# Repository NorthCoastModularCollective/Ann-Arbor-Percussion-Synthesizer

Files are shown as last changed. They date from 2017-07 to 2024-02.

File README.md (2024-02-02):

# Ann Arbor Percussion Synthesizer

A module that generates “abstract” percussion sounds and has a fairly simple interface. It won’t be intended to create “bass drums” or “snares” or “hi hats”, though it’ll probably be able to make things that approximate those sounds. It is raw, dirty, glitchy, lo-fi, and abstract. A Banksy interpretation of a Dali painting of industrial-steam-punk-Qbert. Interacting with it gives you a feeling of exploration and discovery with little emphasis on predictability and reproducibility. However, great care was taken to make the experience not feel like pure chaos and randomness. 

CAUTION: this project is still in development. There are many bugs and gaps. 

Audio Sample, [here](https://soundcloud.com/verzerren/ann-arbor-percussion-synthesizer-v-001-sound-sample)

https://github.com/NorthCoastModularCollective/Ann-Arbor-Percussion-Synthesizer/assets/6989685/e6aa8b81-97f8-49d5-8cca-bbeed19dbfc6

Hardware Overview:
- Teensy 4.1
- Teensy Audio Library
- Eurorack Trigger/Gate input

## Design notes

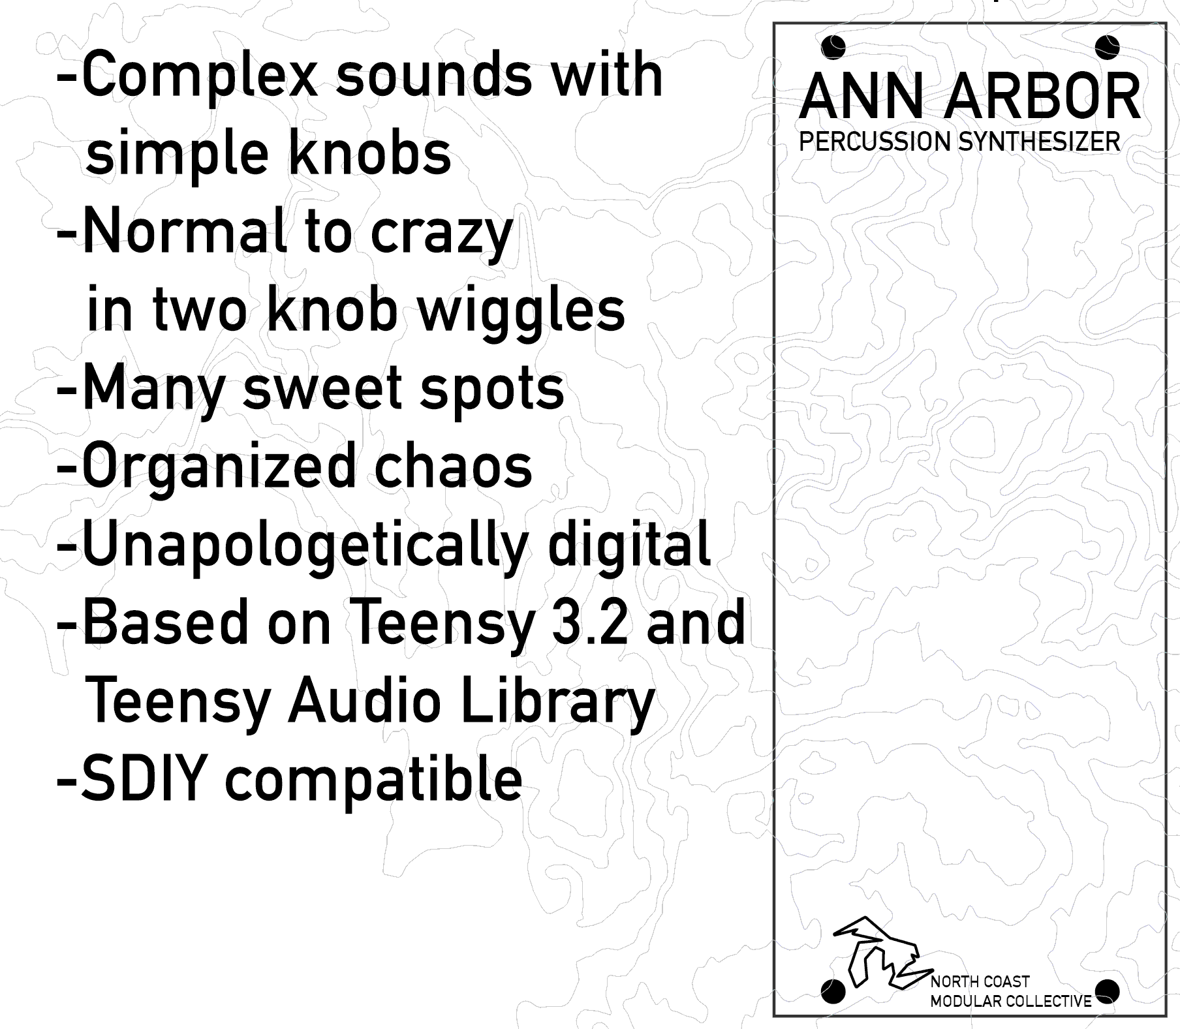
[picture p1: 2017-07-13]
A2Perc.gif

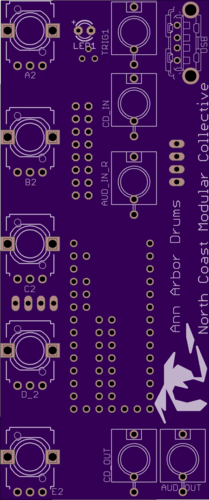
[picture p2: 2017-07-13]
A2_Perc_Front.png

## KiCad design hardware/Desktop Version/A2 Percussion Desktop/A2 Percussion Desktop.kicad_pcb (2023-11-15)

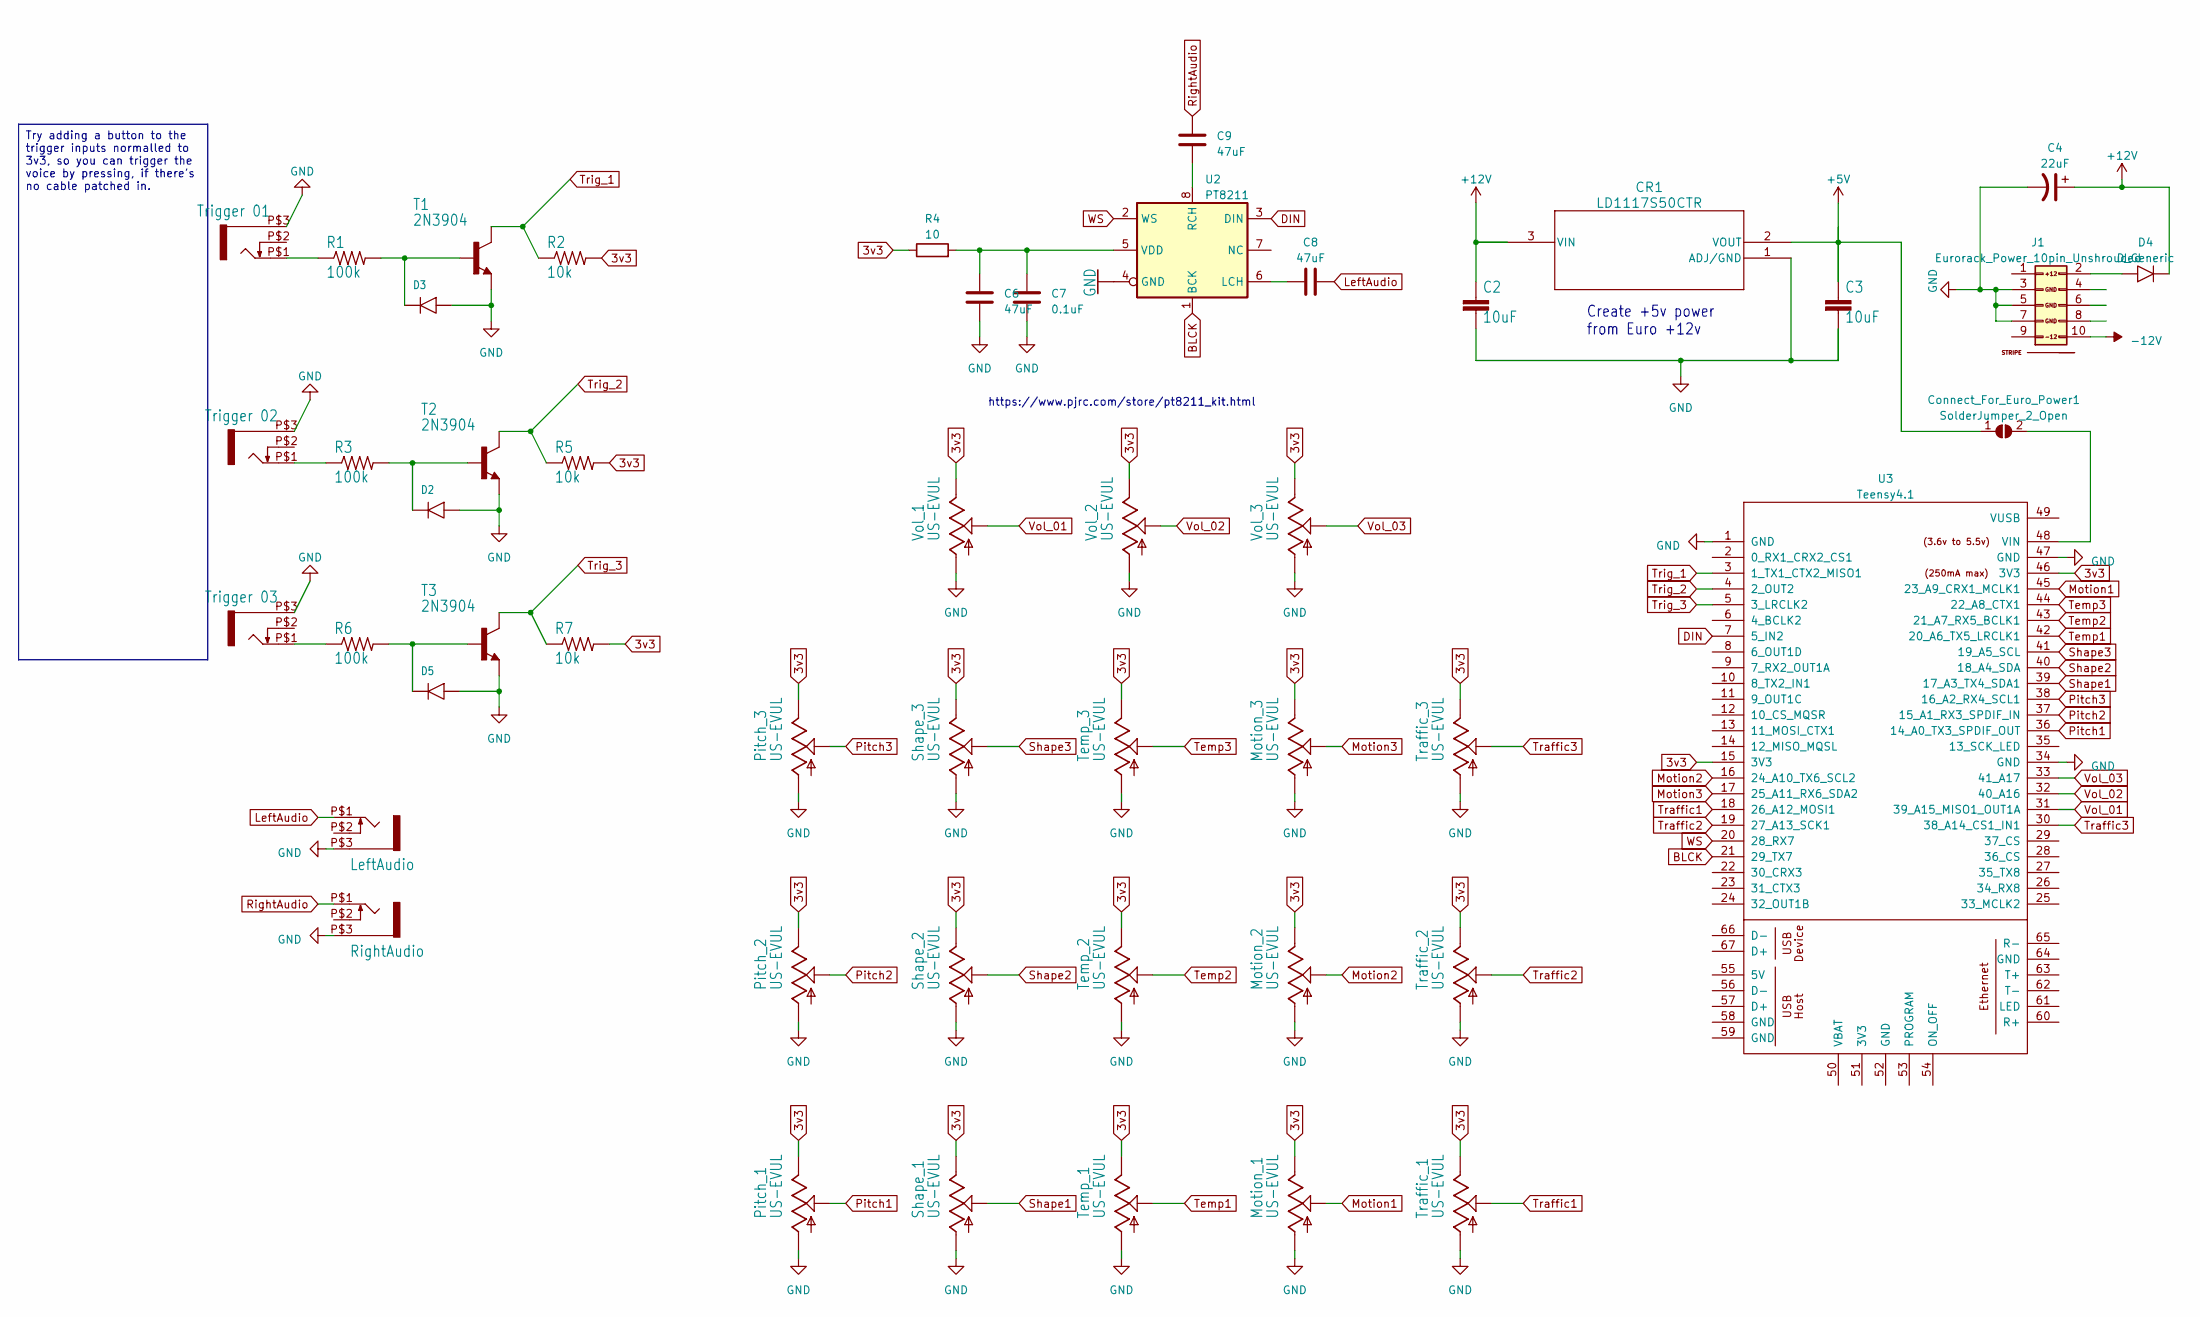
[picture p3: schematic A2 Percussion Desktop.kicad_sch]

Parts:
C2, C3: 10uF; C_Disc_D4.3mm_W1.9mm_P5.00mm
C4: 22uF; CP_Radial_D5.0mm_P2.50mm
C6, C8, C9: 47uF; C_Axial_L5.1mm_D3.1mm_P7.50mm_Horizontal
C7: 0.1uF; C_Axial_L5.1mm_D3.1mm_P7.50mm_Horizontal
CR1: LD1117S50CTR; SOT-223_STM
Connect_For_Euro_Power1: SolderJumper_2_Open; JUMPER_SMD_1x2
D2, D3, D5: DIODESOD-123; D_DO-35_P7.62mm_Horizontal
D4: D_Generic; D_DO-35_P7.62mm_Horizontal
J1: Eurorack_Power_10pin_Unshrouded; Pins_2x05_2.54mm_TH_Europower; Part Number 1-1002FBV0T
LeftAudio1: LeftAudio; WQP-PJ301M-12_JACK
Motion_1, Motion_2, Motion_3: US-EVUL; EVUFXL
Pitch_1, Pitch_2, Pitch_3: US-EVUL; EVUFXL
R1, R3, R6: 100k; R_Axial_DIN0207_L6.3mm_D2.5mm_P7.62mm_Horizontal
R2, R5, R7: 10k; R_Axial_DIN0207_L6.3mm_D2.5mm_P7.62mm_Horizontal
R4: 10; R_Axial_DIN0207_L6.3mm_D2.5mm_P7.62mm_Horizontal
RightAudio1: RightAudio; WQP-PJ301M-12_JACK
Shape_1, Shape_2, Shape_3: US-EVUL; EVUFXL
T1, T2, T3: 2N3904; TO92
TRIG1: Trigger 01; WQP-PJ301M-12_JACK
TRIG2: Trigger 02; WQP-PJ301M-12_JACK
TRIG3: Trigger 03; WQP-PJ301M-12_JACK
Temp_1, Temp_2, Temp_3: US-EVUL; EVUFXL
Traffic_1, Traffic_2, Traffic_3: US-EVUL; EVUFXL
U2: PT8211; VSSOP-8_3.0x3.0mm_P0.65mm
U3: Teensy4.1; Teensy41
Vol_1, Vol_2, Vol_3: US-EVUL; EVUFXL

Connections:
3v3: Motion_1.3 (E), Motion_2.3 (E), Motion_3.3 (E), Pitch_1.3 (E), Pitch_2.3 (E), Pitch_3.3 (E), R2.2, R4.1, R5.2, R7.2, Shape_1.3 (E), Shape_2.3 (E), Shape_3.3 (E), Temp_1.3 (E), Temp_2.3 (E), Temp_3.3 (E), Traffic_1.3 (E), Traffic_2.3 (E), Traffic_3.3 (E), U3.15 (3V3), U3.46 (3V3), Vol_1.3 (E), Vol_2.3 (E), Vol_3.3 (E)
+5V: C3.1, CR1.2 (VOUT), Connect_For_Euro_Power1.1 (A)
+12V: C2.1, C4.1, CR1.3 (VIN), D4.1 (K)
-12V: J1.10 (-12V)
BLCK: U2.1 (BCK), U3.21 (29_TX7)
DIN: U2.3 (DIN), U3.7 (5_IN2)
GND: C2.2, C3.2, C4.2, C6.2, C7.2, CR1.1 (ADJ/GND), D2.2 (A), D3.2 (A), D5.2 (A), J1.3 (GND), J1.5 (GND), J1.7 (GND), LeftAudio1.P$3 (1), Motion_1.1 (A), Motion_2.1 (A), Motion_3.1 (A), Pitch_1.1 (A), Pitch_2.1 (A), Pitch_3.1 (A), RightAudio1.P$3 (1), Shape_1.1 (A), Shape_2.1 (A), Shape_3.1 (A), T1.3 (E), T2.3 (E), T3.3 (E), TRIG1.P$3 (1), TRIG2.P$3 (1), TRIG3.P$3 (1), Temp_1.1 (A), Temp_2.1 (A), Temp_3.1 (A), Traffic_1.1 (A), Traffic_2.1 (A), Traffic_3.1 (A), U2.4 (GND), U3.1 (GND), U3.34 (GND), U3.47 (GND), Vol_1.1 (A), Vol_2.1 (A), Vol_3.1 (A)
LeftAudio: C8.2, LeftAudio1.P$1 (2)
Motion1: Motion_1.2 (S), U3.45 (23_A9_CRX1_MCLK1)
Motion2: Motion_2.2 (S), U3.16 (24_A10_TX6_SCL2)
Motion3: Motion_3.2 (S), U3.17 (25_A11_RX6_SDA2)
unnamed: Connect_For_Euro_Power1.2 (B), U3.48 (VIN)
unnamed: D2.1 (K), R3.2, T2.2 (B)
unnamed: D3.1 (K), R1.2, T1.2 (B)
unnamed: D4.2 (A), J1.2 (+12V)
unnamed: D5.1 (K), R6.2, T3.2 (B)
unnamed: R1.1, TRIG1.P$1 (2)
unnamed: R3.1, TRIG2.P$1 (2)
unnamed: R6.1, TRIG3.P$1 (2)
unnamed: C8.1, U2.6 (LCH)
unnamed: C9.1, U2.8 (RCH)
unnamed: C6.1, C7.1, R4.2, U2.5 (VDD)
Pitch1: Pitch_1.2 (S), U3.36 (14_A0_TX3_SPDIF_OUT)
Pitch2: Pitch_2.2 (S), U3.37 (15_A1_RX3_SPDIF_IN)
Pitch3: Pitch_3.2 (S), U3.38 (16_A2_RX4_SCL1)
RightAudio: C9.2, RightAudio1.P$1 (2)
Shape1: Shape_1.2 (S), U3.39 (17_A3_TX4_SDA1)
Shape2: Shape_2.2 (S), U3.40 (18_A4_SDA)
Shape3: Shape_3.2 (S), U3.41 (19_A5_SCL)
Temp1: Temp_1.2 (S), U3.42 (20_A6_TX5_LRCLK1)
Temp2: Temp_2.2 (S), U3.43 (21_A7_RX5_BCLK1)
Temp3: Temp_3.2 (S), U3.44 (22_A8_CTX1)
Traffic1: Traffic_1.2 (S), U3.18 (26_A12_MOSI1)
Traffic2: Traffic_2.2 (S), U3.19 (27_A13_SCK1)
Traffic3: Traffic_3.2 (S), U3.30 (38_A14_CS1_IN1)
Trig_1: R2.1, T1.1 (C), U3.3 (1_TX1_CTX2_MISO1)
Trig_2: R5.1, T2.1 (C), U3.4 (2_OUT2)
Trig_3: R7.1, T3.1 (C), U3.5 (3_LRCLK2)
Vol_01: U3.31 (39_A15_MISO1_OUT1A), Vol_1.2 (S)
Vol_02: U3.32 (40_A16), Vol_2.2 (S)
Vol_03: U3.33 (41_A17), Vol_3.2 (S)
WS: U2.2 (WS), U3.20 (28_RX7)

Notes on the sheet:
Try adding a button to the trigger inputs normalled to 3v3, so you can trigger the voice by pressing, if there's no cable patched in.
Create +5v power from Euro +12v
https://www.pjrc.com/store/pt8211_kit.html

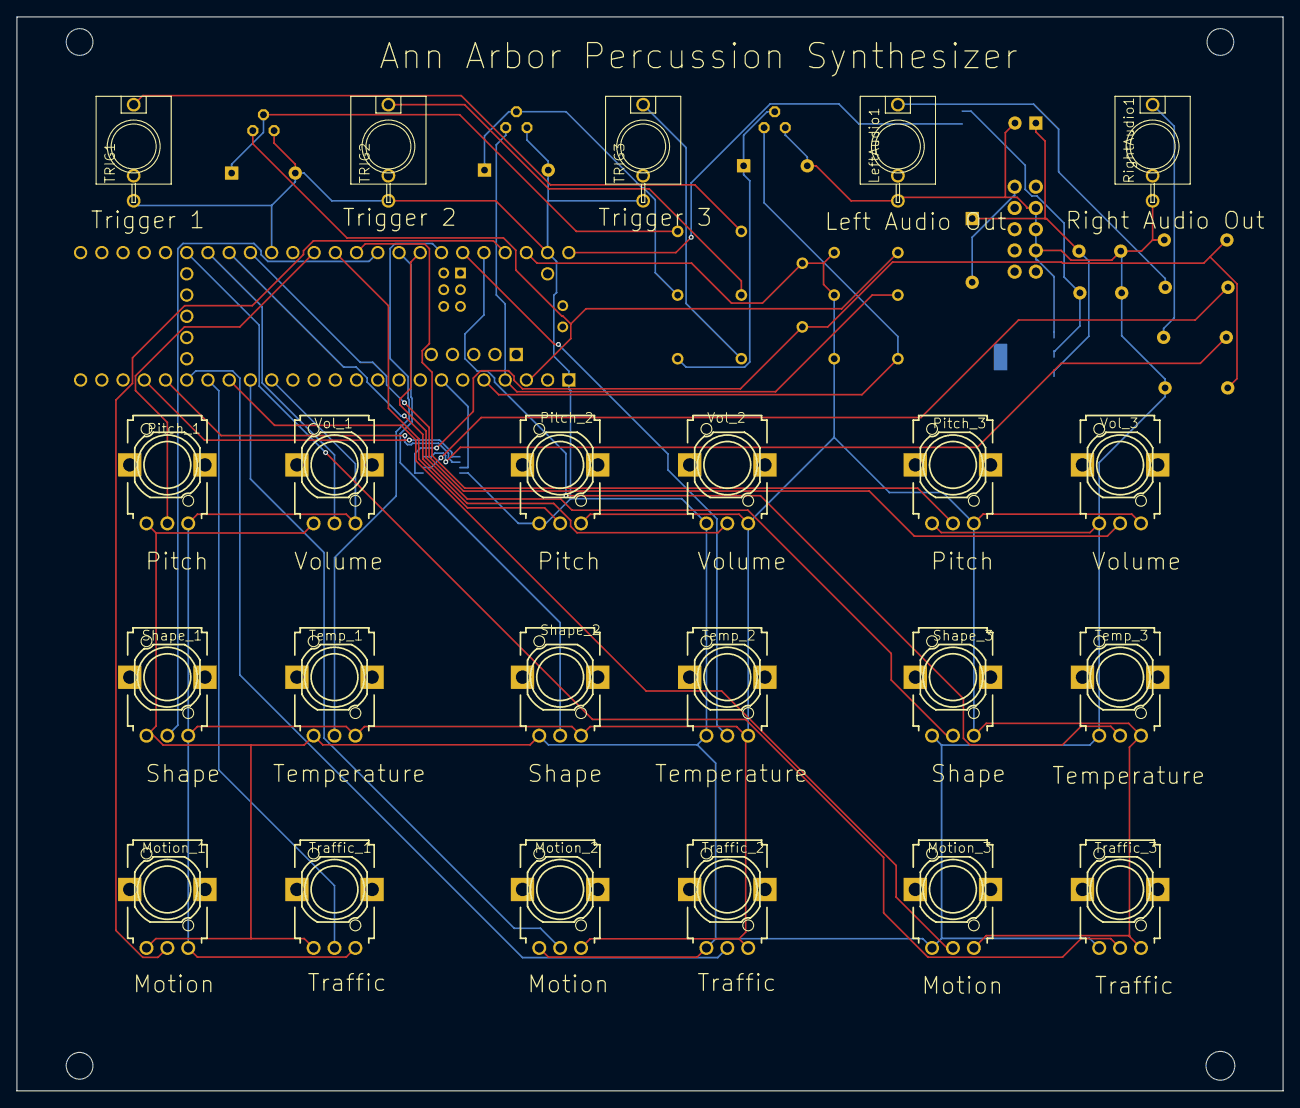
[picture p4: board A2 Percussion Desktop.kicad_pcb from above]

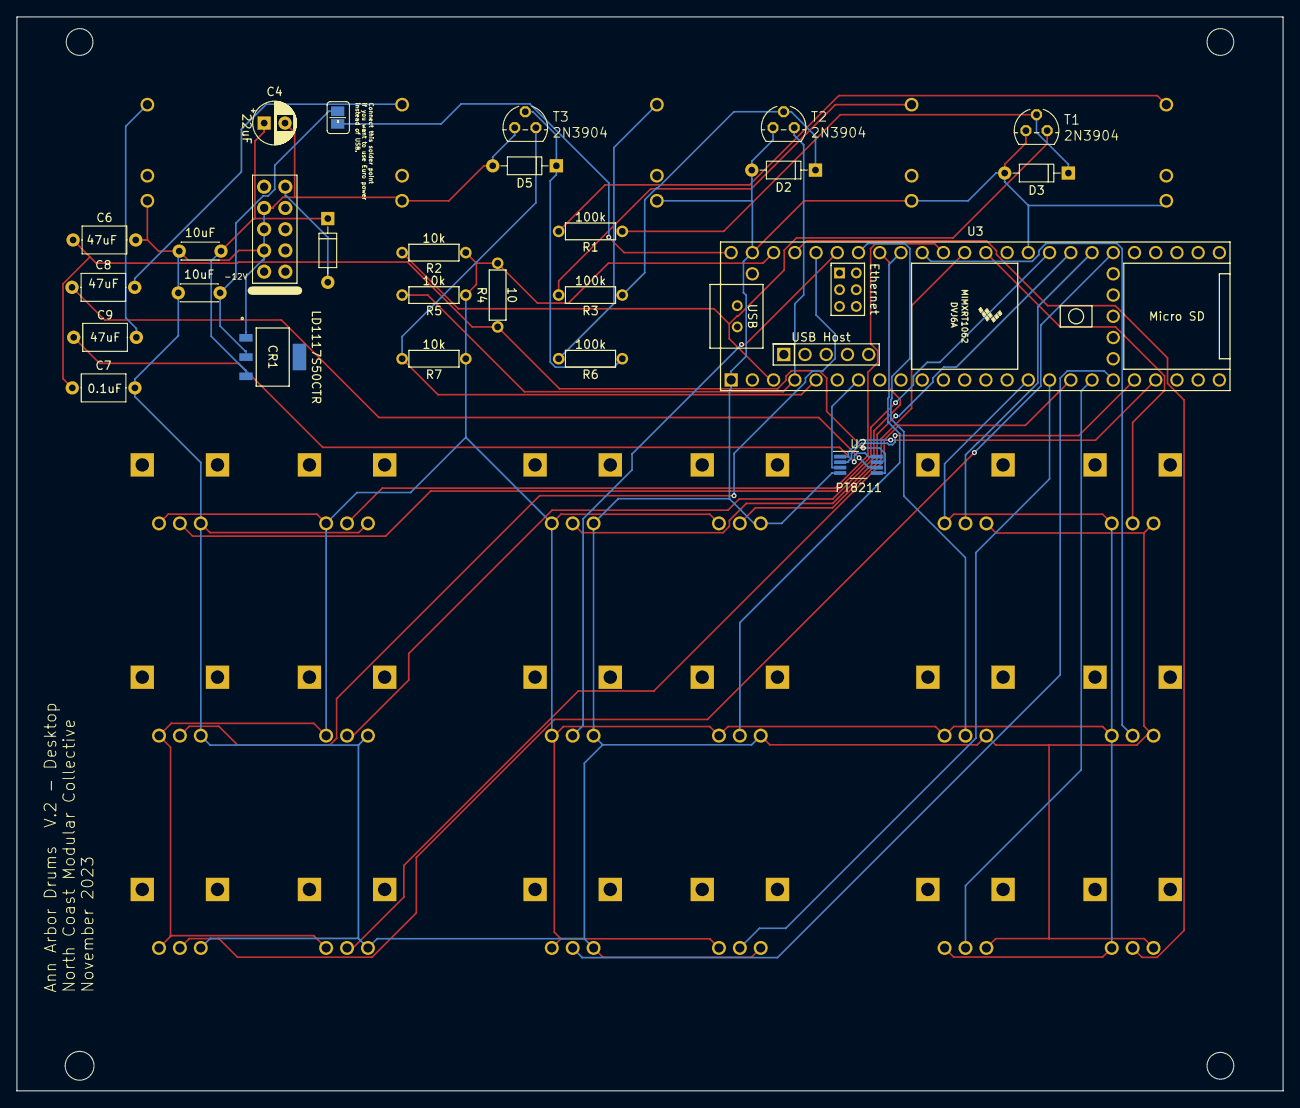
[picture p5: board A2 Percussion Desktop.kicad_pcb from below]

Board: 2 copper layers, 151.5 x 128.5 mm, 49 parts (26 on the bottom side), 41 nets.

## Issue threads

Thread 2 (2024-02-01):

Footprint for PT8211 chip is too small

joebauer, 2024-02-01:

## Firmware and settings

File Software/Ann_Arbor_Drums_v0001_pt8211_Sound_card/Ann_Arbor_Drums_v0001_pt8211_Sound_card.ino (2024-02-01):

/* 
  North Coast Modular Collective Ann Arbor Drums
  Version .001 July 2017
  ---------------------------------------------------------
  Copyright 2017 North Coast Modular Collective
  MIT License:
  Permission is hereby granted, free of charge, to any person obtaining a copy of this software and associated 
  documentation files (the "Software"), to deal in the Software without restriction, including without limitation 
  the rights to use, copy, modify, merge, publish, distribute, sublicense, and/or sell copies of the Software, and 
  to permit persons to whom the Software is furnished to do so, subject to the following conditions:

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
  THE SOFTWARE IS PROVIDED "AS IS", WITHOUT WARRANTY OF ANY KIND, EXPRESS OR IMPLIED, INCLUDING BUT NOT LIMITED TO 
  THE WARRANTIES OF MERCHANTABILITY, FITNESS FOR A PARTICULAR PURPOSE AND NONINFRINGEMENT. IN NO EVENT SHALL THE 
  AUTHORS OR COPYRIGHT HOLDERS BE LIABLE FOR ANY CLAIM, DAMAGES OR OTHER LIABILITY, WHETHER IN AN ACTION OF CONTRACT, 
  TORT OR OTHERWISE, ARISING FROM, OUT OF OR IN CONNECTION WITH THE SOFTWARE OR THE USE OR OTHER DEALINGS IN THE SOFTWARE.
  ----------------------------------------------------------  


  This version uses the pt8211 audio shield
*/


/* Notes to self for future development
Look into MIDI callbacks for handling MIDI input to control the voices https://github.com/FortySevenEffects/arduino_midi_library/wiki/Using-Callbacks


*/

//For modifications, the code from the "GUItool" below can be imported into the Teensy audio system design tool at https://www.pjrc.com/teensy/gui/index.html
#include <Audio.h>
#include <Wire.h>
#include <SPI.h>
#include <SD.h>
#include <SerialFlash.h>

// GUItool: begin automatically generated code
AudioSynthWaveformSine   sine1;          //xy=90,398
AudioSynthWaveformSineModulated sine_fm1;       //xy=260,432
AudioSynthWaveform       waveform1;      //xy=262,328
AudioSynthNoiseWhite     noise1;         //xy=264,493
AudioSynthWaveformPWM    pwm1;           //xy=266,376
AudioSynthSimpleDrum     drum1;          //xy=270,278
AudioMixer4              mixer3;         //xy=437,334
AudioEffectEnvelope      envelope2;      //xy=582,445
AudioEffectEnvelope      envelope1;      //xy=584,333
AudioEffectBitcrusher    bitcrusher1;    //xy=735,334
AudioMixer4              mixer1;         //xy=893,352
AudioFilterStateVariable filter1;        //xy=1041,321
AudioMixer4              mixer2;         //xy=1185,350
AudioOutputPT8211        pt8211_1;       //xy=1338,352
AudioConnection          patchCord1(sine1, pwm1);
AudioConnection          patchCord2(sine1, sine_fm1);
AudioConnection          patchCord3(sine_fm1, 0, mixer3, 3);
AudioConnection          patchCord4(waveform1, 0, mixer3, 1);
AudioConnection          patchCord5(noise1, envelope2);
AudioConnection          patchCord6(pwm1, 0, mixer3, 2);
AudioConnection          patchCord7(drum1, 0, mixer3, 0);
AudioConnection          patchCord8(mixer3, envelope1);
AudioConnection          patchCord9(envelope2, 0, mixer1, 1);
AudioConnection          patchCord10(envelope1, bitcrusher1);
AudioConnection          patchCord11(bitcrusher1, 0, mixer1, 0);
AudioConnection          patchCord12(mixer1, 0, filter1, 0);
AudioConnection          patchCord13(mixer1, 0, mixer2, 2);
AudioConnection          patchCord14(filter1, 0, mixer2, 0);
AudioConnection          patchCord15(filter1, 2, mixer2, 1);
AudioConnection          patchCord16(mixer2, 0, pt8211_1, 0);
AudioConnection          patchCord17(mixer2, 0, pt8211_1, 1);
// GUItool: end automatically generated code




//AudioControlSGTL5000 codec;

//  Set up all the pin number variables
//trigger inputs
int Trigger1Pin = 1; 

//Potentiometers
int pA2 = A0;
int pB2 = A3;
int pC2 = A6;
int pD2 = A9;
int pE2 = A12;

//variables for tracking the trigger states
int playTimes = 0; 

float Drum1Level = 1.0; //Audio level appears to require a float. see if this can be an int!!!!!!!!!!!!!!
float mapf(float x, float in_min, float in_max, float out_min, float out_max)
{
  return (x - in_min) * (out_max - out_min) / (in_max - in_min) + out_min;
}

void setup() {
Serial.begin(9600);

// Get the board ready
  AudioMemory(200);
//  codec.enable();
//  codec.volume(1); //0-1. crank it. We'll control volume per drum channel with the mixers.
  
//Now set up the oscillators  
  AudioNoInterrupts(); 
//Set up drum1
  drum1.frequency(440);
  drum1.length(500);
  drum1.secondMix(0.0);
  drum1.pitchMod(0.50);
//Set up FX
  bitcrusher1.bits(16);
  bitcrusher1.sampleRate(44100);
//Set up noise sources
  noise1.amplitude(.5);
//Set up Envelopes
  envelope1.attack(.1);
  envelope1.decay(50);
  envelope1.hold(0);
  envelope1.sustain(0);
//  envelope3.release(0);
  envelope2.attack(.1);
  envelope2.decay(0);
  envelope2.hold(0);
  envelope2.sustain(0);
//Set up the mixers (for "Level" settings)
  mixer1.gain(0, 1); //gain(channel, level); just pass the audio through ("level" may be any floating point number from 0 to 32767)  
  mixer2.gain(0, 1); 
  mixer2.gain(1, 0);
  mixer2.gain(2, 0);
  mixer2.gain(3, 1);
  mixer3.gain(0, 1);
  mixer3.gain(1, 0);
  mixer3.gain(2, .5);
  mixer3.gain(3, 0);

//PWM
pwm1.frequency(440);
pwm1.amplitude(.9);

//Set up sine waves for LFO
sine1.amplitude(1);
sine1.frequency(0.1);

//FM
sine_fm1.amplitude(1);


//Set up Digital Pins
//triggers
  pinMode(Trigger1Pin, INPUT); //D1 is a digital input




  AudioInterrupts();



} // end void setup

elapsedMillis msec = 0; //here for timing the troubleshooting loop at the bottom

void loop() {  //Main loop for the run state
//========LFO=====================
//The LFO might be working, but I can't get a good read or sample of it yet. 
float LFOLevel;
//sine1.frequency(map(analogRead(pD2), 0, 1023, 0.001, 100)); //set LFO frequency based on motion knob position


//=======PITCH KNOB=================
  int Drum1Freq = map(analogRead(pA2), 0, 1023, 20, 2500); 
  drum1.frequency(Drum1Freq);
  pwm1.frequency(Drum1Freq / 2);
  sine_fm1.frequency(Drum1Freq);


//===========SHAPE KNOB=================
//Set the shape of the envelope so that on the potentiomenter, left of half point is a ramp up (/|) 
//and right of half point is a decay slope (|\). 
  int Drum1Length = map(analogRead(pB2), 0, 1023, 1, 2000);
  if (Drum1Length > 1000) {  //right of center
  drum1.length(Drum1Length - 1000); 
  envelope1.attack(0);
  envelope1.delay(0);
  envelope1.hold(0);
  envelope1.decay(Drum1Length - 1000);
  envelope1.sustain(0);
  } else { //left of center
  drum1.length(abs(Drum1Length - 1000));   
  envelope1.sustain(0);
  envelope1.attack(abs(Drum1Length - 1000));  
  }
 
//=================TEMPURATURE KNOB==================

//Set modulation knob so that at center there is no effect, left of center is "colder" and right of center is "warmer"
  int ModLevel1 = map(analogRead(pC2), 0, 1023, 1, 2000); 
  mixer2.gain(0, mapf(ModLevel1, 1, 2000, 0, 1.0));
  mixer2.gain(1, mapf(ModLevel1, 1, 2000, 1.0, 0));

     
  filter1.frequency(abs(ModLevel1 - 1000)*4);
  
  if (ModLevel1 > 1000) { //right of center
    envelope2.decay(0);
    noise1.amplitude(0);
 //  filter1.frequency(map(abs(ModLevel1 - 1000), 1, 1000, 4410, 500));
   drum1.secondMix(mapf(abs(ModLevel1 - 1000), 1, 2000, 0, 1.0));

  } else { //left of center
    noise1.amplitude(mapf(abs(ModLevel1 - 1000), 1, 2000, .001, .2));
    envelope2.decay(map(abs(ModLevel1 - 1000), 1, 2000, 0, 70)); 
//  filter1.frequency(map(abs(ModLevel1 - 1000), 1, 2000, 1100, 4410));
  }


//============MOTION KNOB=================
int MotionLevel1 = map(analogRead(pD2), 0, 1023, 1, 2000);


if (MotionLevel1 > 1000) { //Right of center
    drum1.pitchMod(.5); //have normal pitch mod level
    filter1.resonance(mapf(abs(MotionLevel1 - 1000), 1, 2000, .7, 5));
    sine1.frequency(mapf(abs(MotionLevel1 - 1000), 0, 1023, 0.001, 100)); //set LFO frequency based on motion knob position
} else {
    drum1.pitchMod(mapf(MotionLevel1, 1, 2000, 1, 0)); //bend the pitch down as it plays  
}


//============TEETH KNOB===================
int TeethLevel1 = map(analogRead(pE2), 0, 1023, 1, 2000);

if (TeethLevel1 > 1000) { //Right of center
  bitcrusher1.bits(map(TeethLevel1, 1, 2000, 24, 2));
  bitcrusher1.sampleRate(map(TeethLevel1, 1, 2000, 50200, 1));
  mixer3.gain(3, mapf(abs(TeethLevel1 - 1000), 1, 2000, 0, .5)); 
  mixer3.gain(2,0); //Make sure PWM isn't on
} else { //if left of center...
  bitcrusher1.sampleRate(map(TeethLevel1, 1, 2000, 1, 50200));
  mixer3.gain(2, mapf(abs(TeethLevel1 - 1000), 1, 2000, 0, .2)); 
  mixer3.gain(3, 0); //make sure FM isn't on
}  




//TRIGGER THE DRUM:
if (digitalRead(Trigger1Pin) == LOW) 
{
    if (playTimes < 1){
      drum1.noteOn();   //Play the drum1 sound just once
      envelope1.noteOn(); //drum envelope
      envelope2.noteOn(); //noise source
//      digitalWrite(Trig1LED, LOW);
    playTimes = playTimes + 1;
    }
    if (playTimes > 1){
      playTimes = playTimes + 1;       //Chill, don't play anything, and increment
//       digitalWrite(Trig1LED, HIGH);
    }
} 
if ((digitalRead(Trigger1Pin) == HIGH)){
  playTimes = 0;
//  digitalWrite(Trig1LED, HIGH);
  envelope1.noteOff();
  envelope2.noteOff();
}

//============TROUBLESHOOTING==================
//  Here for troubleshooting when Trigger isn't available
  if (msec >= 500) {
//DRUM1
//digitalWrite(1, LOW); //Uncomment this and...
 
  msec = 0;
  } else {
//digitalWrite(1, HIGH); //...also uncomment this, in order to test without having to send it a trigger
  }
    
} //End of main Loop

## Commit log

2017-07-13 Version .001 - WORK IN PROGRESS
    An alpha version of the board. Work in progress.
    [A2 Drums.brd, A2 Drums.sch]
2017-07-15 Added link to audio sample
2023-11-12 Starting back over with version 1 and will rebuild up from there
    after a long hiatus, going to try and pick this one back up again. Restarting from an earlier version because some of the later versions had a lot of experiments that were me not knowing what I was d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
    [A2 Drums.brd, A2 Drums.kicad_pcb, A2 Drums.kicad_sch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]
2023-11-12 Set up a bare basic test/validation script for Teensy and audio board to test for health
2023-11-12 Reverted back to a very old version of the code. This is super duper bad code. Don't use it yet.
    [Ann_Arbor_Drums_v0001.ino]
2023-11-15 V2 of hardware and made a version of the software that uses the pt8211 chip for audio
    [A2 Drums.kicad_sch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]
